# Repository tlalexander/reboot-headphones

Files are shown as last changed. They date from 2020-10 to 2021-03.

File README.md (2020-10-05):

# reboot headphones
Open Source over the ear headphones designed by Taylor from [Reboot.love](http://reboot.love)  

CC0 Licensed: Use this information for any purpose. <3  

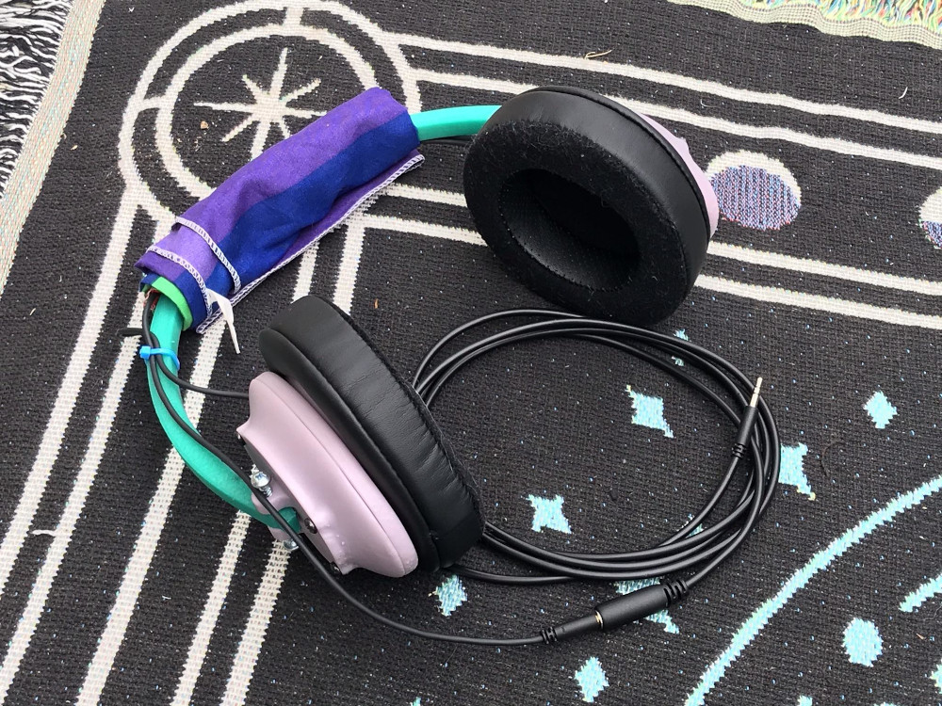
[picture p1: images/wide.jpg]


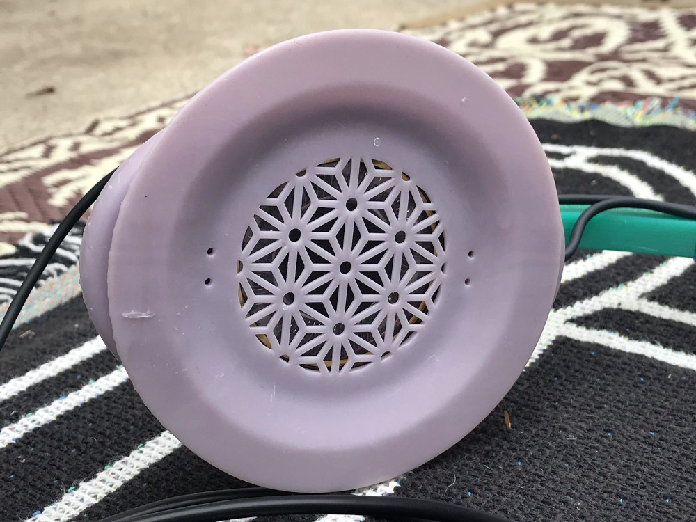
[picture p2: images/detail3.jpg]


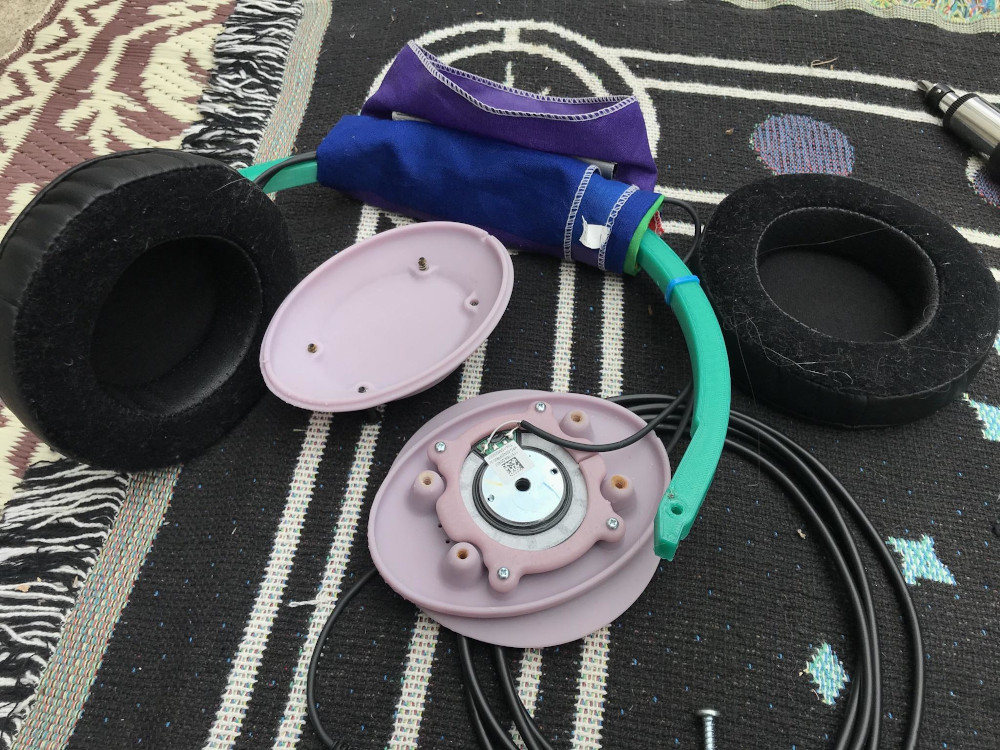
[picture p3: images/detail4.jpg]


Full image album here:  
https://imgur.com/gallery/dxpr4aY  

All you need to print the headphones is in this repo. However if you would like  
to edit the files yourself, sign up for a free OnShape account here:  
https://www.onshape.com/products/free  

Once you're signed in, open the following link and copy the workspace. Then you  
can make them yours!  

https://cad.onshape.com/documents/f0e9a74700c2078061cb0b53/w/2cc319a5f7a2c9805d7fe5c2/e/41e5238346e91c978379d343  

About
===

A great sounding pair of large over the ear headphones for 50mm drivers.  
Primarily designed for printing on a liquid SLA or MLSA style printer, not a  
normal FDM/FFF printer!  

Seriously though, the sound quality really blew me away. I compared to my friend's  
expensive headphones and these are surprisingly comparable. Way better than  
my cheap $40 bluetooth headphones and really has made it a joy to listen to music!  

I printed mine on my Elegoo Mars Pro, a $300 printer. This would also work with  
the Anycubic Photon, Prusa SL1, etc.  

If you like the idea of open source hardware and want to talk about it, check  
out my website at http://reboot.love and join the discussion!  

Parts required
===

* Find the STL files zipped up in the 3d_models folder.  
* Print one headband on an FFF/FDM style printer.  
* Print one head pad, then two of everything else using an MSLA or other resin  
* based printer.  
* Except do not print the "Foam Ear Pad".  
* I found that the "Speaker Casing" part prints nicely in a fully vertical  
* orientation. I was actually able to print two side by side.  

Be advised: The headband is not adjustable. You will likely need to log in to  
onshape and change the headband dimensions, then export that part as STL and  
print your updated version. If you want a cool project, experiment with  
designing an adjustable headband and please let me know when you've done it!  

I designed these headphones for the following foam earpads.  
https://www.brainwavzaudio.com/collections/earpads-round-xl/products/headphone-memory-foam-earpads-xl-pu-leather  
or:  
https://www.brainwavzaudio.com/collections/earpads-round-xl/products/headphone-memory-foam-earpads-xl-size-micro-suede  
see also the product on Amazon US:  
https://www.amazon.com/gp/product/B078HJ5GND/  

You will need two of these or similar drivers:  
https://www.digikey.com/en/products/detail/peerless-by-tymphany/HPD-50N25PR00-32/6211129  
Driver Manufacturer: Peerless by Tymphany  
Driver Part Number: HPD-50N25PR00-32  

You will need to solder a headphone cable to the drivers.  
I purchased this cord and cut one end off.  
https://www.digikey.com/en/products/detail/tensility-international-corp/10-02047/5844710  

I wired mine so that the above cord hangs off the left side by just a few inches.  
I then use the following extension to connect to the audio source.  
https://www.digikey.com/en/products/detail/tensility-international-corp/10-02136/7606585  

This serves as a strain relief if you catch the cord and can make transportation  
easier.  

Finally you will require several different sizes of plastite-style screws.  
Plastite screws work extremely well for holding plastic parts together, and are  
in many cases much easier to use than your standard M3 screw and nut.  

I used these screws in the design:  
https://www.amazon.com/gp/product/B00GDYECN8/  
https://www.amazon.com/dp/product/B00GDY8I92/  

And then I need to check but the inside of the headphones uses one of these sizes:  
https://www.amazon.com/gp/product/B00GDXW3OE/  
https://www.amazon.com/gp/product/B00GDXU4WM/  

Sorry but I will try to update that with certainty when I have a moment to open  
them up.

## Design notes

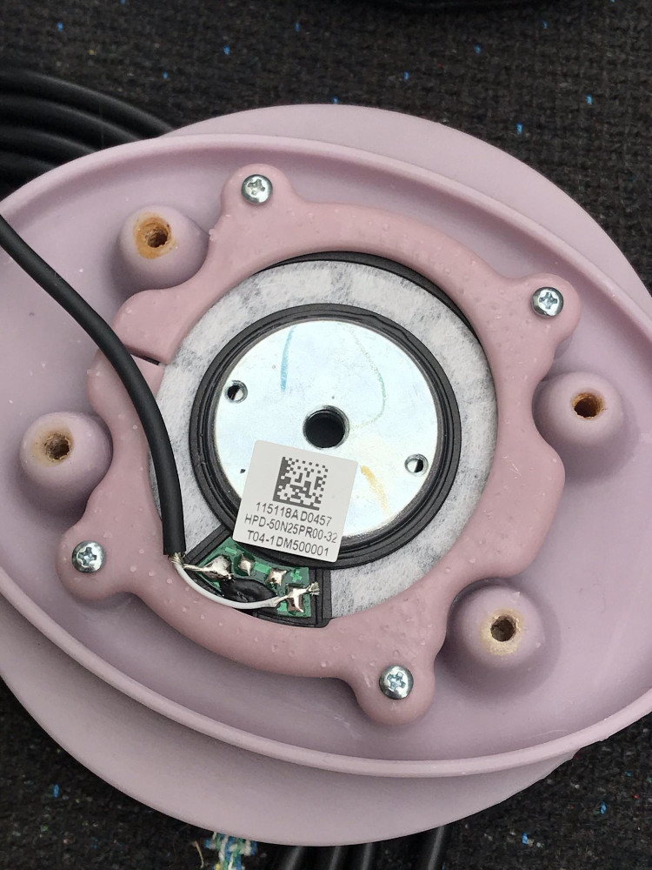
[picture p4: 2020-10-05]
images/detail2.jpg

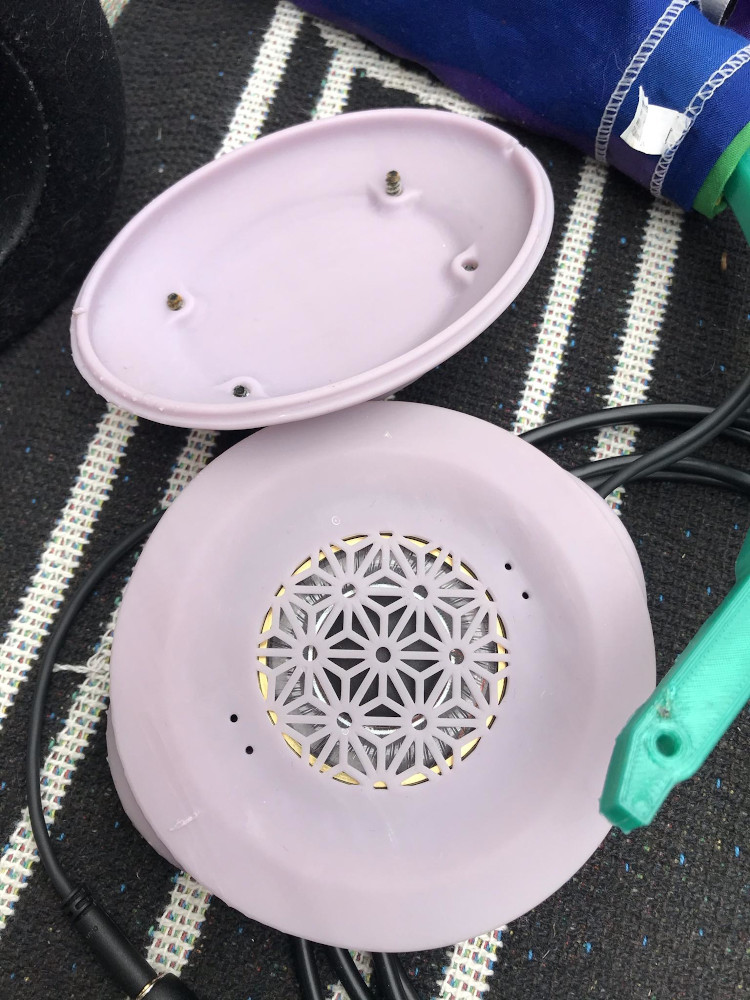
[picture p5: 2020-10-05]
images/detail1.jpg

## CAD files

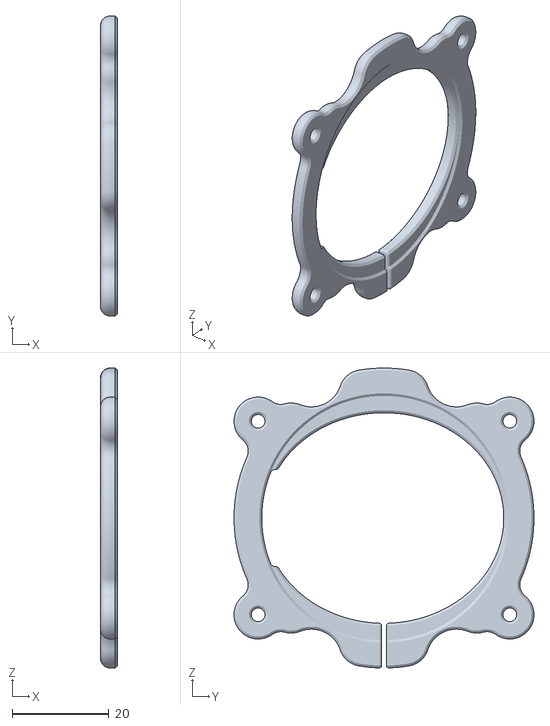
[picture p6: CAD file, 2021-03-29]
3d_models/Headphones 50mm oval - Speaker Bracket.stl
3.50 x 62.0 x 62.0

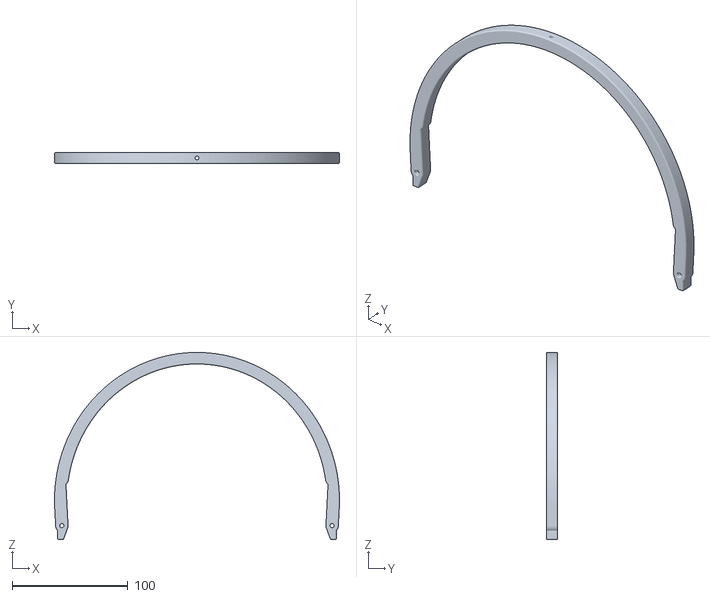
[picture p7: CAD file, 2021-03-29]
3d_models/Headphones 50mm oval - Headband.stl
246.8 x 9.80 x 162.0

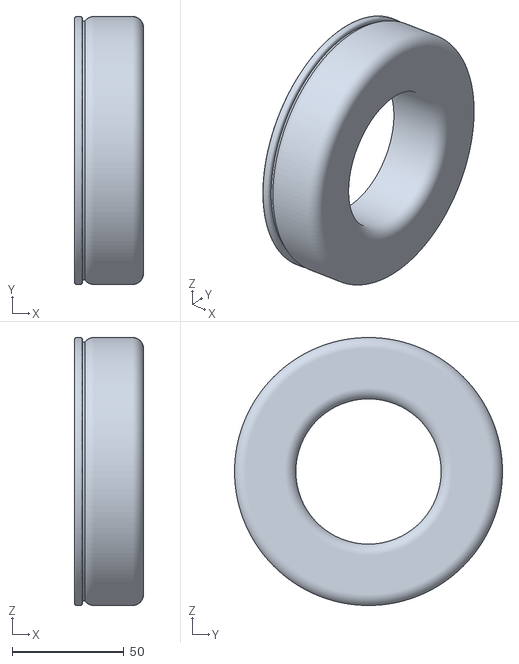
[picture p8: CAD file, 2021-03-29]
3d_models/Headphones 50mm oval - Foam Ear Pad.stl
31.0 x 120.0 x 120.0

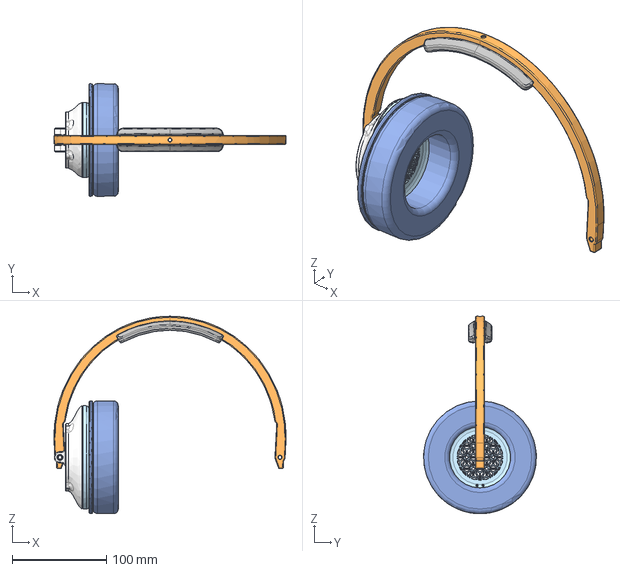
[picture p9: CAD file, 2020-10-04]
3d_models/Headphones 50mm oval.step
246.7 x 119.8 x 210.0 mm

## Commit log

2020-10-04 Add 3D models and fill out readme
    [Headphones 50mm oval.step]
2021-03-29 Unpack zip file of STLs and removed the archive. Committing its contents.
    [Headphones 50mm oval - Foam Ear Pad.stl, Headphones 50mm oval - Headband.stl, Headphones 50mm oval - Speaker Bracket.stl]
